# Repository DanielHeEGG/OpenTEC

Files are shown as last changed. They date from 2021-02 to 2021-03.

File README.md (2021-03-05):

# OpenTEC
OpenTEC is a low-cost, DIY temperature controller. Designed to be used as a controller for temperature chambers.

The controller board works by taking in temperature readings and driving thermoelectric coolers (TEC) in order to control the temperature inside the chamber.

This can be also used as a controller for **terribly ineffcient** DIY fridges and air conditioners.

This project is currently a work in progress.

## Features
- Built-in LCD screen and user interface.
- Up to 4 analog temperature sensor inputs.
- I2C port for peripherals.
- Discrete H-bridge driving currents up to 8 amps.
- All SMD components selected to be assembled by [JLCPCB](https://jlcpcb.com/).

## Structure
`Hardware/` - PCB source files, designed with [KiCAD](https://kicad.org/).

`Fabrication/` - Exported fabrication files (Gerber, BOM, POS).

`Firmware/` - Firmware source code, written with [PlatformIO IDE](https://platformio.org/).

## License
- The hardware portion of the project (everything under `Hardware/` and `Fabrication/`) is licensed under the [CERN Open Hardware Licence](https://cern-ohl.web.cern.ch/home).
- The firmware portion of the project (everything under `Firmware/`, with exceptions, see below) is licensed under the [3-Clause BSD License](https://opensource.org/licenses/BSD-3-Clause).

#### Exceptions
- [FreeRTOSConfig.h](Firmware/include/FreeRTOSConfig.h) `Copyright 2017 Amazon.com, Inc. or its affiliates.`
- [stm32f1xx_hal_conf.h](Firmware/include/stm32f1xx_hal_conf.h) `Copyright 2017 STMicroelectronics.`

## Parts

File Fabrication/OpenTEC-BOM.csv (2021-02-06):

Designator | Comment | Footprint
C1 | 100uF | Capacitor_SMD:CP_Elec_6.3x5.3
C2, C3, C16, C17 | 10uF | Capacitor_SMD:C_0805_2012Metric
C4 | 4.7uF | Capacitor_SMD:C_0805_2012Metric
C5, C6, C7, C8, C10 | 100nF | Capacitor_SMD:C_0402_1005Metric
C9, C18, C19 | 1uF | Capacitor_SMD:C_0805_2012Metric
C11 | 10nF | Capacitor_SMD:C_0402_1005Metric
C12, C13 | 30pF | Capacitor_SMD:C_0603_1608Metric
D1 | POWER_LED | LED_SMD:LED_0603_1608Metric
D2 | STATUS_LED | LED_SMD:LED_0603_1608Metric
D3, D4 | B5819W | Diode_SMD:D_SOD-123
R2, R10 | 100 | Resistor_SMD:R_0402_1005Metric
R3, R4, R5, R11, R12 | 2.2K | Resistor_SMD:R_0402_1005Metric
U1 | STM32F103C8T6 | Package_QFP:LQFP-48_7x7mm_P0.5mm
U2 | AMS1117-3.3 | Package_TO_SOT_SMD:SOT-223-3_TabPin2
U3, U4 | IR2104 | Package_SO:SOIC-8_3.9x4.9mm_P1.27mm
Y1 | 16MHz | Crystal:Crystal_SMD_3225-4Pin_3.2x2.5mm

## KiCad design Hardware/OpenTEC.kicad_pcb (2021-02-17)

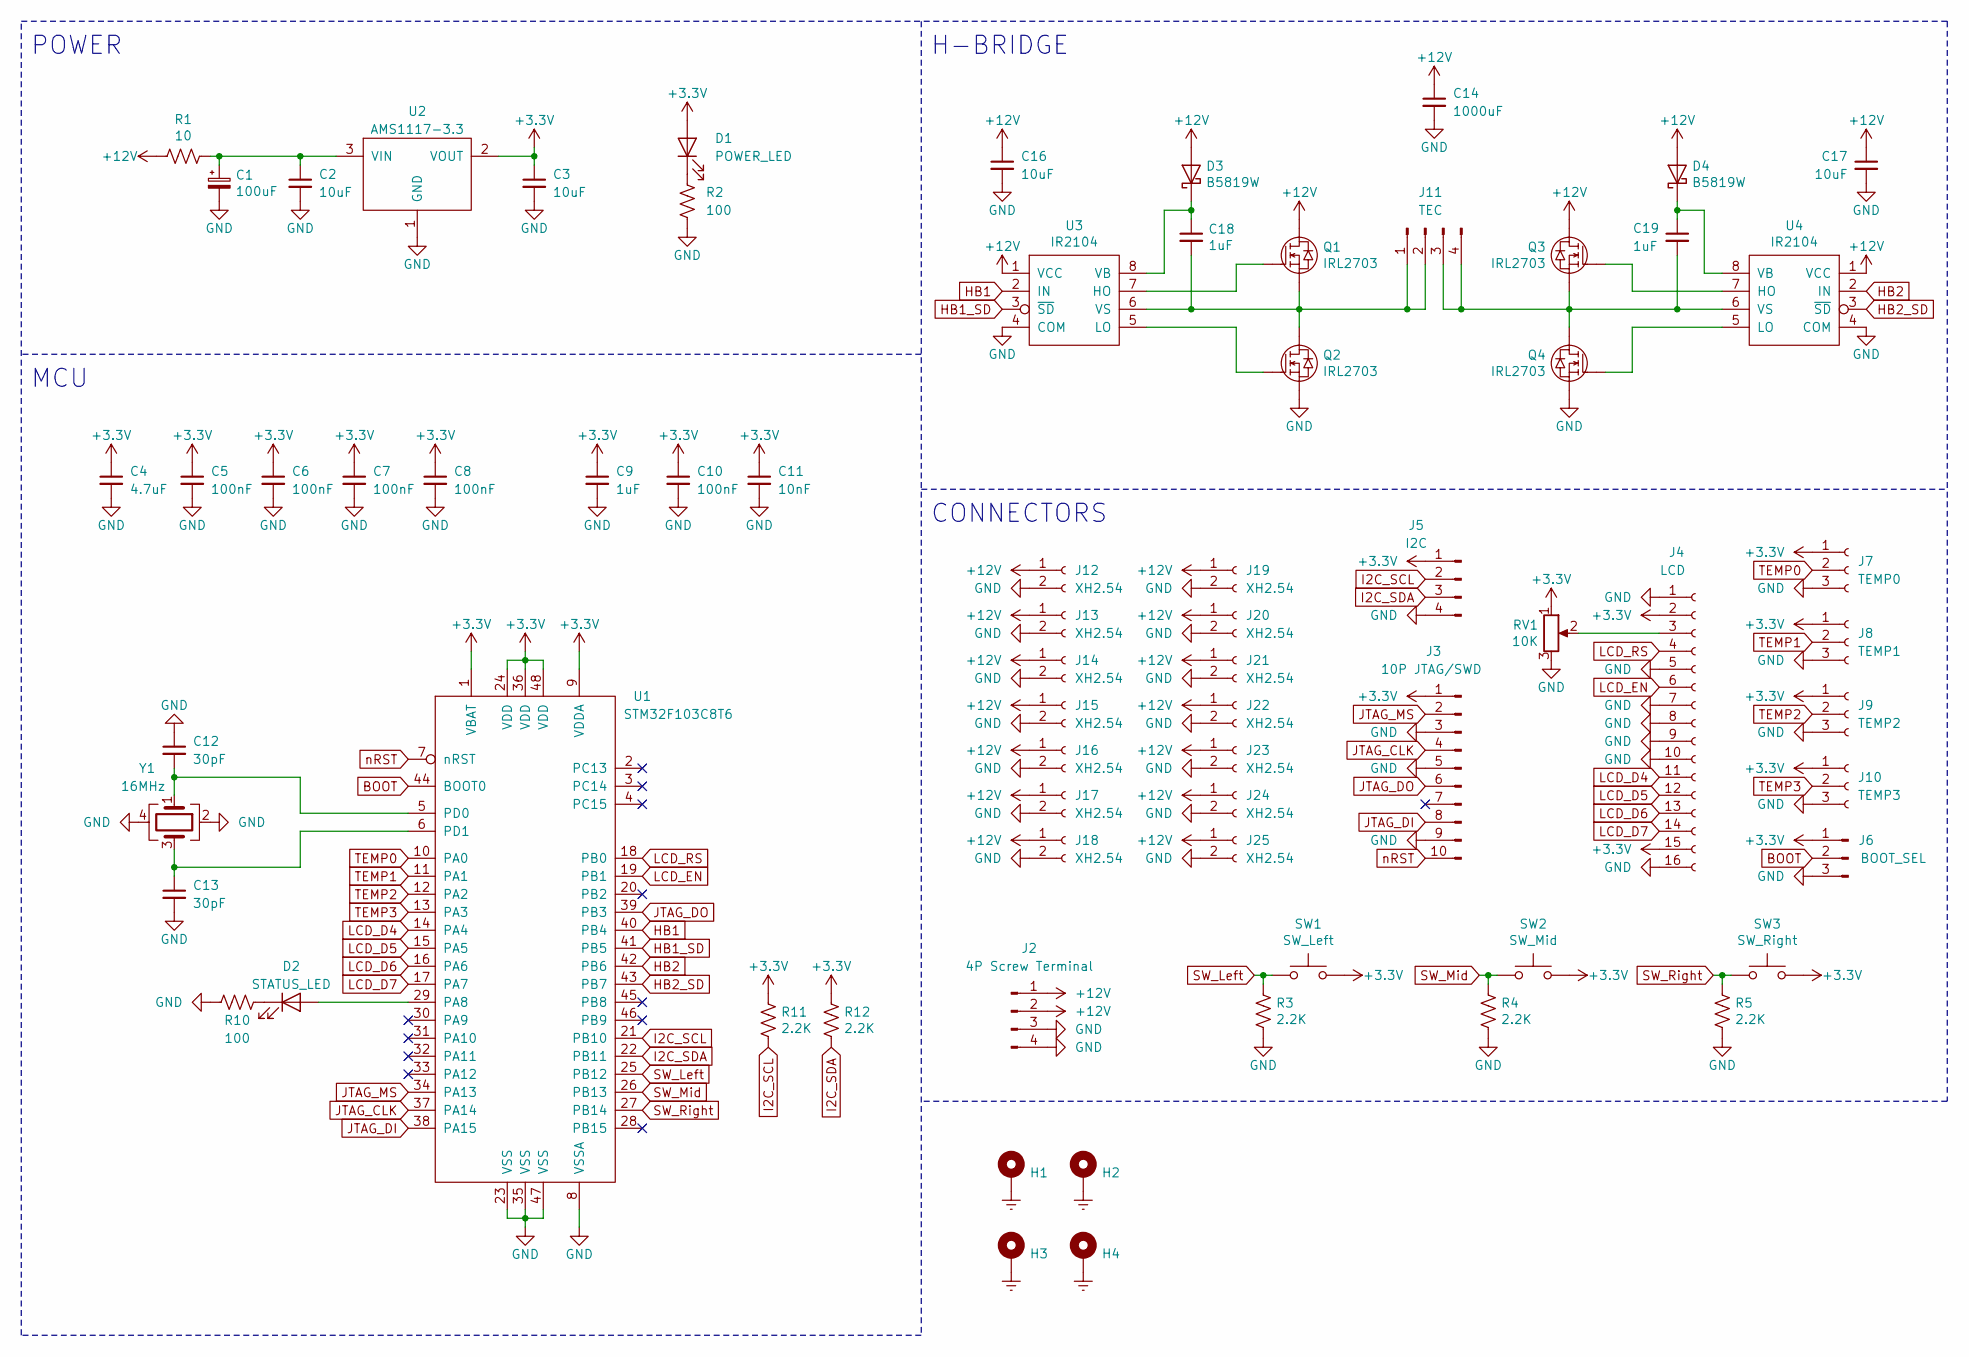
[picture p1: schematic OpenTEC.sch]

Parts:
C1: 100uF; CP_Elec_6.3x5.3
C2, C3, C16, C17: 10uF; C_0805_2012Metric
C4: 4.7uF; C_0805_2012Metric
C5, C6, C7, C8, C10: 100nF; C_0402_1005Metric
C9, C18, C19: 1uF; C_0805_2012Metric
C11: 10nF; C_0402_1005Metric
C12, C13: 30pF; C_0603_1608Metric
C14: 1000uF; CP_Radial_D13.0mm_P5.00mm
D1: POWER_LED; LED_0603_1608Metric
D2: STATUS_LED; LED_0603_1608Metric
D3, D4: B5819W; D_SOD-123
H1, H2, H3, H4: MountingHole_3.2mm_M3_Pad_Via
J2: 4P Screw Terminal; TerminalBlock_bornier-4_P5.08mm
J3: 10P JTAG/SWD; PinHeader_2x05_P2.54mm_Vertical
J4: LCD; PinSocket_1x16_P2.54mm_Vertical
J5: I2C; PinHeader_1x04_P2.54mm_Vertical
J6: BOOT_SEL; PinHeader_1x03_P2.54mm_Vertical
J7: TEMP0; PinSocket_1x03_P2.54mm_Vertical
J8: TEMP1; PinSocket_1x03_P2.54mm_Vertical
J9: TEMP2; PinSocket_1x03_P2.54mm_Vertical
J10: TEMP3; PinSocket_1x03_P2.54mm_Vertical
J11: TEC; TerminalBlock_bornier-4_P5.08mm
J12, J13, J14, J15, J16, J17, J18, J19, J20, J21, J22, J23, J24, J25: XH2.54; JST_XH_B2B-XH-A_1x02_P2.50mm_Vertical
Q1, Q2, Q3, Q4: IRL2703; TO-220-3_Vertical
R1: 10; R_Axial_Power_L20.0mm_W6.4mm_P22.40mm
R2, R10: 100; R_0402_1005Metric
R3, R4, R5, R11, R12: 2.2K; R_0402_1005Metric
RV1: 10K; Potentiometer_Bourns_3386P_Vertical
SW1: SW_Left; SW_PUSH_6mm
SW2: SW_Mid; SW_PUSH_6mm
SW3: SW_Right; SW_PUSH_6mm
U1: STM32F103C8T6; LQFP-48_7x7mm_P0.5mm
U2: AMS1117-3.3; SOT-223-3_TabPin2
U3, U4: IR2104; SOIC-8_3.9x4.9mm_P1.27mm
Y1: 16MHz; Crystal_SMD_3225-4Pin_3.2x2.5mm

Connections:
+3V3: C3.1, C4.1, C5.1, C6.1, C7.1, C8.1, C9.1, C10.1, C11.1, D1.2 (A), J3.1, J4.2, J4.15, J5.1, J6.1, J7.1, J8.1, J9.1, J10.1, R11.1, R12.1, RV1.1, SW1.2, SW2.2, SW3.2, U1.1 (VBAT), U1.9 (VDDA), U1.24 (VDD), U1.36 (VDD), U1.48 (VDD), U2.2 (VOUT)
+12V: C14.1, C16.1, C17.1, D3.2 (A), D4.2 (A), J2.1, J2.2, J12.1, J13.1, J14.1, J15.1, J16.1, J17.1, J18.1, J19.1, J20.1, J21.1, J22.1, J23.1, J24.1, J25.1, Q1.2, Q3.2, R1.2, U3.1 (VCC), U4.1 (VCC)
BOOT: J6.2, U1.44 (BOOT0)
Earth: H1.1, H2.1, H3.1, H4.1
GND: C1.2, C2.2, C3.2, C4.2, C5.2, C6.2, C7.2, C8.2, C9.2, C10.2, C11.2, C12.1, C13.2, C14.2, C16.2, C17.2, J2.3, J2.4, J3.3, J3.5, J3.9, J4.1, J4.5, J4.7, J4.8, J4.9, J4.10, J4.16, J5.4, J6.3, J7.3, J8.3, J9.3, J10.3, J12.2, J13.2, J14.2, J15.2, J16.2, J17.2, J18.2, J19.2, J20.2, J21.2, J22.2, J23.2, J24.2, J25.2, Q2.3, Q4.3, R2.2, R3.2, R4.2, R5.2, R10.2, RV1.3, U1.8 (VSSA), U1.23 (VSS), U1.35 (VSS), U1.47 (VSS), U2.1 (GND), U3.4 (COM), U4.4 (COM), Y1.2, Y1.4
HB1: U1.40 (PB4), U3.2 (IN)
HB1_SD: U1.41 (PB5), U3.3 (~SD)
HB2: U1.42 (PB6), U4.2 (IN)
HB2_SD: U1.43 (PB7), U4.3 (~SD)
I2C_SCL: J5.2, R11.2, U1.21 (PB10)
I2C_SDA: J5.3, R12.2, U1.22 (PB11)
JTAG_CLK: J3.4, U1.37 (PA14)
JTAG_DI: J3.8, U1.38 (PA15)
JTAG_DO: J3.6, U1.39 (PB3)
JTAG_MS: J3.2, U1.34 (PA13)
LCD_D4: J4.11, U1.14 (PA4)
LCD_D5: J4.12, U1.15 (PA5)
LCD_D6: J4.13, U1.16 (PA6)
LCD_D7: J4.14, U1.17 (PA7)
LCD_EN: J4.6, U1.19 (PB1)
LCD_RS: J4.4, U1.18 (PB0)
unnamed: C1.1, C2.1, R1.1, U2.3 (VIN)
unnamed: C12.2, U1.5 (PD0), Y1.1
unnamed: C13.1, U1.6 (PD1), Y1.3
unnamed: C18.1, D3.1 (K), U3.8 (VB)
unnamed: C18.2, J11.1, J11.2, Q1.3, Q2.2, U3.6 (VS)
unnamed: C19.1, D4.1 (K), U4.8 (VB)
unnamed: C19.2, J11.3, J11.4, Q3.3, Q4.2, U4.6 (VS)
unnamed: D1.1 (K), R2.1
unnamed: D2.1 (K), R10.1
unnamed: D2.2 (A), U1.29 (PA8)
unnamed: J4.3, RV1.2
unnamed: Q1.1, U3.7 (HO)
unnamed: Q2.1, U3.5 (LO)
unnamed: Q3.1, U4.7 (HO)
unnamed: Q4.1, U4.5 (LO)
SW_Left: R3.1, SW1.1, U1.25 (PB12)
SW_Mid: R4.1, SW2.1, U1.26 (PB13)
SW_Right: R5.1, SW3.1, U1.27 (PB14)
TEMP0: J7.2, U1.10 (PA0)
TEMP1: J8.2, U1.11 (PA1)
TEMP2: J9.2, U1.12 (PA2)
TEMP3: J10.2, U1.13 (PA3)
nRST: J3.10, U1.7 (nRST)

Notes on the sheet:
POWER
MCU
H-BRIDGE
CONNECTORS

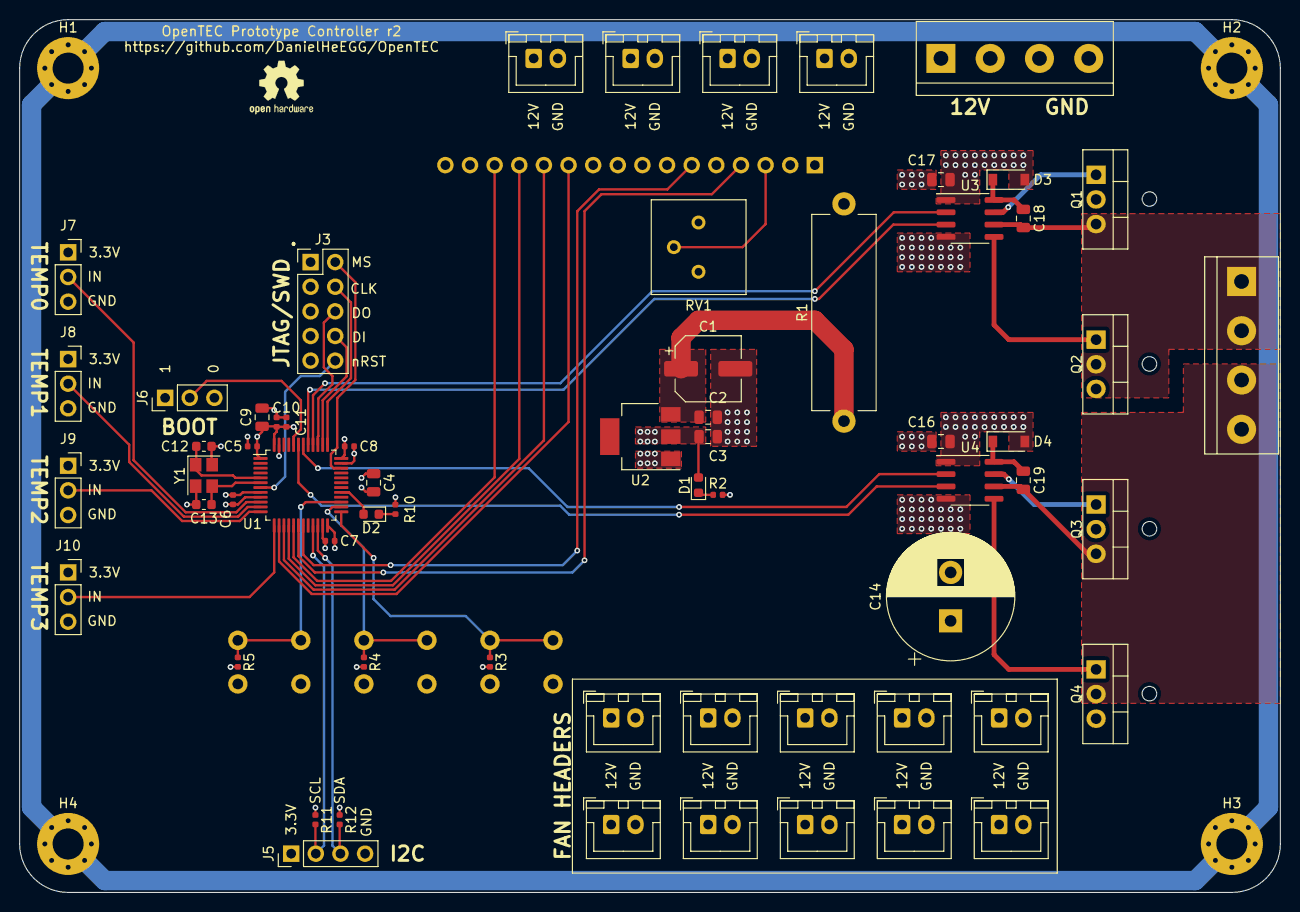
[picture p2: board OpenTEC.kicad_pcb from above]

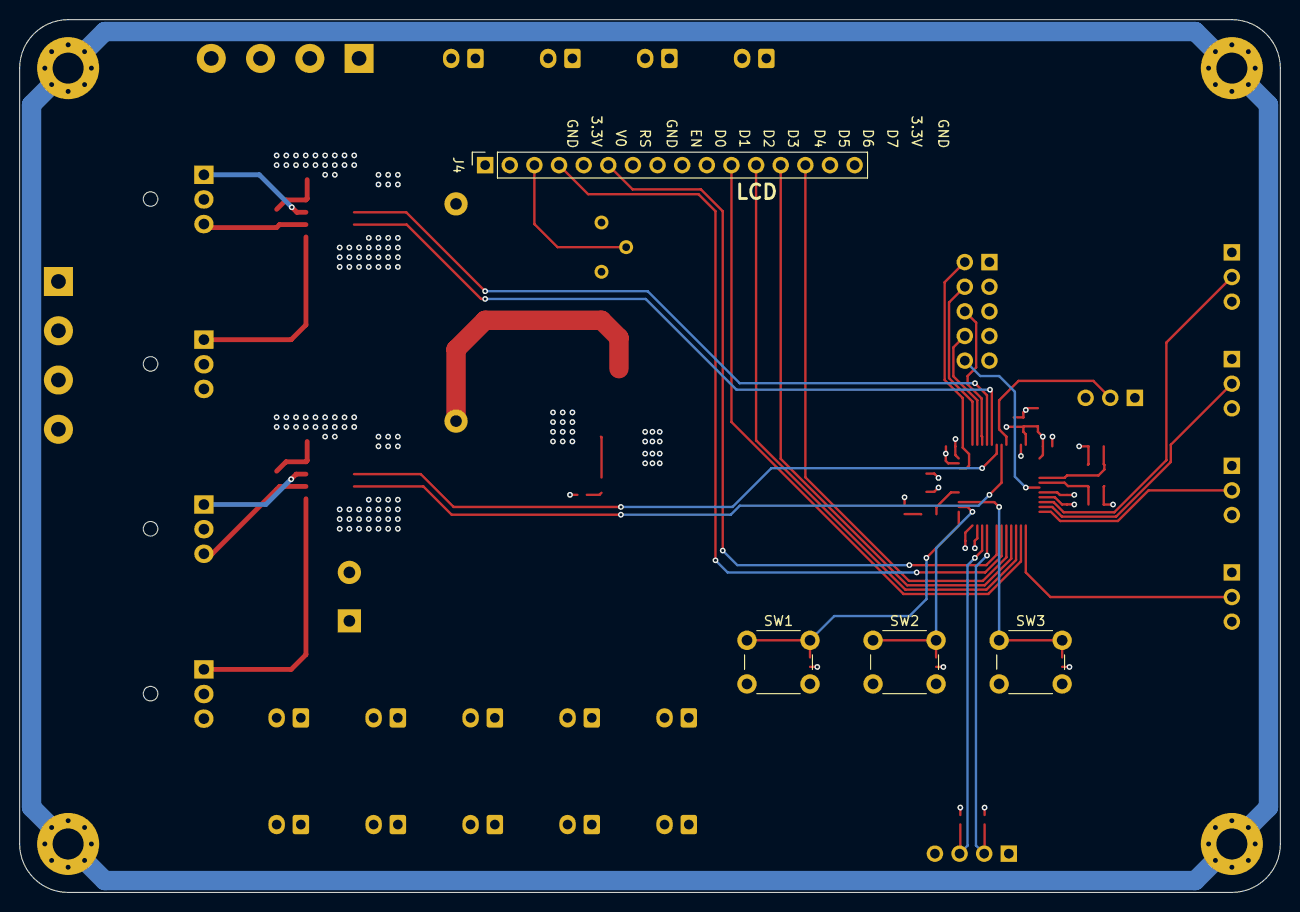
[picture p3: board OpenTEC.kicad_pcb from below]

Board: 4 copper layers, 130.0 x 90.0 mm, 71 parts (4 on the bottom side), 44 nets.

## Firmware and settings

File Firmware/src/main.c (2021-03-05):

/**
  ******************************************************************************
  * @file           : main.c
  * @brief          : Main program body.
  ******************************************************************************
  */

#include "main.h"
#include "cmsis_os.h"
#include "adc.h"
#include "i2c.h"
#include "tim.h"
#include "gpio.h"

void SystemClock_Config(void);
void MX_FREERTOS_Init(void);

/**
  * @brief  Entry point.
  * @retval int
  */
int main(void) {
    HAL_Init();

    SystemClock_Config();

    MX_GPIO_Init();
    MX_ADC1_Init();
    MX_I2C2_Init();
    MX_TIM3_Init();
    MX_TIM4_Init();

    osKernelInitialize();
    MX_FREERTOS_Init();

    osKernelStart();

    while (1) {}
}

/**
  * @brief System clock configuration.
  * @retval None
  */
void SystemClock_Config(void) {
    RCC_OscInitTypeDef RCC_OscInitStruct;
    RCC_OscInitStruct.OscillatorType = RCC_OSCILLATORTYPE_HSE;
    RCC_OscInitStruct.HSEState = RCC_HSE_ON;
    RCC_OscInitStruct.HSEPredivValue = RCC_HSE_PREDIV_DIV2;
    RCC_OscInitStruct.HSIState = RCC_HSI_ON;
    RCC_OscInitStruct.PLL.PLLState = RCC_PLL_ON;
    RCC_OscInitStruct.PLL.PLLSource = RCC_PLLSOURCE_HSE;
    RCC_OscInitStruct.PLL.PLLMUL = RCC_PLL_MUL9;
    if (HAL_RCC_OscConfig(&RCC_OscInitStruct) != HAL_OK) Error_Handler();

    RCC_ClkInitTypeDef RCC_ClkInitStruct;
    RCC_ClkInitStruct.ClockType = RCC_CLOCKTYPE_HCLK | RCC_CLOCKTYPE_SYSCLK | RCC_CLOCKTYPE_PCLK1 | RCC_CLOCKTYPE_PCLK2;
    RCC_ClkInitStruct.SYSCLKSource = RCC_SYSCLKSOURCE_PLLCLK;
    RCC_ClkInitStruct.AHBCLKDivider = RCC_SYSCLK_DIV1;
    RCC_ClkInitStruct.APB1CLKDivider = RCC_HCLK_DIV2;
    RCC_ClkInitStruct.APB2CLKDivider = RCC_HCLK_DIV1;
    if (HAL_RCC_ClockConfig(&RCC_ClkInitStruct, FLASH_LATENCY_2) != HAL_OK) Error_Handler();

    RCC_PeriphCLKInitTypeDef PeriphClkInit;
    PeriphClkInit.PeriphClockSelection = RCC_PERIPHCLK_ADC;
    PeriphClkInit.AdcClockSelection = RCC_ADCPCLK2_DIV6;
    if (HAL_RCCEx_PeriphCLKConfig(&PeriphClkInit) != HAL_OK) Error_Handler();
}

/**
  * @brief  Period elapsed callback in non blocking mode.
  * @param  htim : TIM handle
  * @retval None
  */
void HAL_TIM_PeriodElapsedCallback(TIM_HandleTypeDef *htim) {
    if (htim -> Instance == TIM1) HAL_IncTick();
}

/**
  * @brief  Error handler.
  * @retval None
  */
void Error_Handler(void) {
    __disable_irq();
    while (1) {}
}

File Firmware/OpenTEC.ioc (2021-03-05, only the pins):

Mcu.UserName=STM32F103C8Tx
PA0-WKUP.GPIO_Label=TEMP0
PA0-WKUP.Signal=ADCx_IN0
PA1.GPIO_Label=TEMP1
PA1.Signal=ADCx_IN1
PA13.Signal=SYS_JTMS-SWDIO
PA14.Signal=SYS_JTCK-SWCLK
PA15.Signal=SYS_JTDI
PA2.GPIO_Label=TEMP2
PA2.Signal=ADCx_IN2
PA3.GPIO_Label=TEMP3
PA3.Signal=ADCx_IN3
PA4.GPIO_Label=LCD_D4
PA4.Signal=GPIO_Output
PA5.GPIO_Label=LCD_D5
PA5.Signal=GPIO_Output
PA6.GPIO_Label=LCD_D6
PA6.Signal=GPIO_Output
PA7.GPIO_Label=LCD_D7
PA7.Signal=GPIO_Output
PA8.GPIO_Label=STATUS_LED
PA8.Signal=GPIO_Output
PB0.GPIO_Label=LCD_RS
PB0.Signal=GPIO_Output
PB1.GPIO_Label=LCD_EN
PB1.Signal=GPIO_Output
PB10.Signal=I2C2_SCL
PB11.Signal=I2C2_SDA
PB12.GPIO_Label=SW_L
PB12.Signal=GPXTI12
PB13.GPIO_Label=SW_M
PB13.Signal=GPXTI13
PB14.GPIO_Label=SW_R
PB14.Signal=GPXTI14
PB3.Signal=SYS_JTDO-TRACESWO
PB4.GPIO_Label=HB1
PB4.Signal=S_TIM3_CH1
PB5.GPIO_Label=HB1_SD
PB5.Signal=GPIO_Output
PB6.GPIO_Label=HB2
PB6.Signal=S_TIM4_CH1
PB7.GPIO_Label=HB2_SD
PB7.Signal=GPIO_Output
PD0-OSC_IN.Signal=RCC_OSC_IN
PD1-OSC_OUT.Signal=RCC_OSC_OUT

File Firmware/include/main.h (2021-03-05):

/**
  ******************************************************************************
  * @file           : main.h
  * @brief          : Header for main.c file.
  ******************************************************************************
  */

#include "stm32f1xx_hal.h"

void Error_Handler(void);

#define TEMP0_Pin GPIO_PIN_0
#define TEMP0_GPIO_Port GPIOA
#define TEMP1_Pin GPIO_PIN_1
#define TEMP1_GPIO_Port GPIOA
#define TEMP2_Pin GPIO_PIN_2
#define TEMP2_GPIO_Port GPIOA
#define TEMP3_Pin GPIO_PIN_3
#define TEMP3_GPIO_Port GPIOA
#define LCD_D4_Pin GPIO_PIN_4
#define LCD_D4_GPIO_Port GPIOA
#define LCD_D5_Pin GPIO_PIN_5
#define LCD_D5_GPIO_Port GPIOA
#define LCD_D6_Pin GPIO_PIN_6
#define LCD_D6_GPIO_Port GPIOA
#define LCD_D7_Pin GPIO_PIN_7
#define LCD_D7_GPIO_Port GPIOA
#define LCD_RS_Pin GPIO_PIN_0
#define LCD_RS_GPIO_Port GPIOB
#define LCD_EN_Pin GPIO_PIN_1
#define LCD_EN_GPIO_Port GPIOB
#define SW_L_Pin GPIO_PIN_12
#define SW_L_GPIO_Port GPIOB
#define SW_L_EXTI_IRQn EXTI15_10_IRQn
#define SW_M_Pin GPIO_PIN_13
#define SW_M_GPIO_Port GPIOB
#define SW_M_EXTI_IRQn EXTI15_10_IRQn
#define SW_R_Pin GPIO_PIN_14
#define SW_R_GPIO_Port GPIOB
#define SW_R_EXTI_IRQn EXTI15_10_IRQn
#define STATUS_LED_Pin GPIO_PIN_8
#define STATUS_LED_GPIO_Port GPIOA
#define HB1_Pin GPIO_PIN_4
#define HB1_GPIO_Port GPIOB
#define HB1_SD_Pin GPIO_PIN_5
#define HB1_SD_GPIO_Port GPIOB
#define HB2_Pin GPIO_PIN_6
#define HB2_GPIO_Port GPIOB
#define HB2_SD_Pin GPIO_PIN_7
#define HB2_SD_GPIO_Port GPIOB

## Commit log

2021-01-24 Finish schematic
    [OpenTEC.sch]
2021-01-25 Add I2C connector
    [OpenTEC.sch]
2021-01-25 Ground unused pins on LCD connector
    [OpenTEC.sch]
2021-01-25 Add temperature sensor connectors
    [OpenTEC.sch]
2021-01-25 Add fan headers
    [OpenTEC.sch]
2021-01-25 Add footprints to components
    [OpenTEC.sch]
2021-01-25 Finish PCB layout, export fabrication files
    [OpenTEC-BOM.csv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]
2021-01-26 Change H-bridge design
    [OpenTEC-BOM.csv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]
2021-01-27 Fix USB Micro B connector footprint
    [OpenTEC-BOM.csv, OpenTEC.kicad_pcb, OpenTEC.sch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]
2021-02-03 Add BFC to H-bridge
    [OpenTEC-BOM.csv, OpenTEC.kicad_pcb, OpenTEC.sch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]
2021-02-03 Remove unused USB port and 5V LDO
    [OpenTEC-BOM.csv, OpenTEC.kicad_pcb, OpenTEC.sch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]
2021-02-04 Add RC filter to 3.3V LDO input
    [OpenTEC-BOM.csv, OpenTEC.kicad_pcb, OpenTEC.sch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]
2021-02-04 Add control push buttons
    [OpenTEC.kicad_pcb, OpenTEC.sch]
2021-02-06 Fix H-bridge supply voltage
    [OpenTEC-BOM.csv, OpenTEC.kicad_pcb, OpenTEC.sch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]
2021-02-17 Add more vias to H-bridge
    [OpenTEC.kicad_pcb, OpenTEC.sch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]
2021-03-05 Generate framework code with STM32CubeMX
